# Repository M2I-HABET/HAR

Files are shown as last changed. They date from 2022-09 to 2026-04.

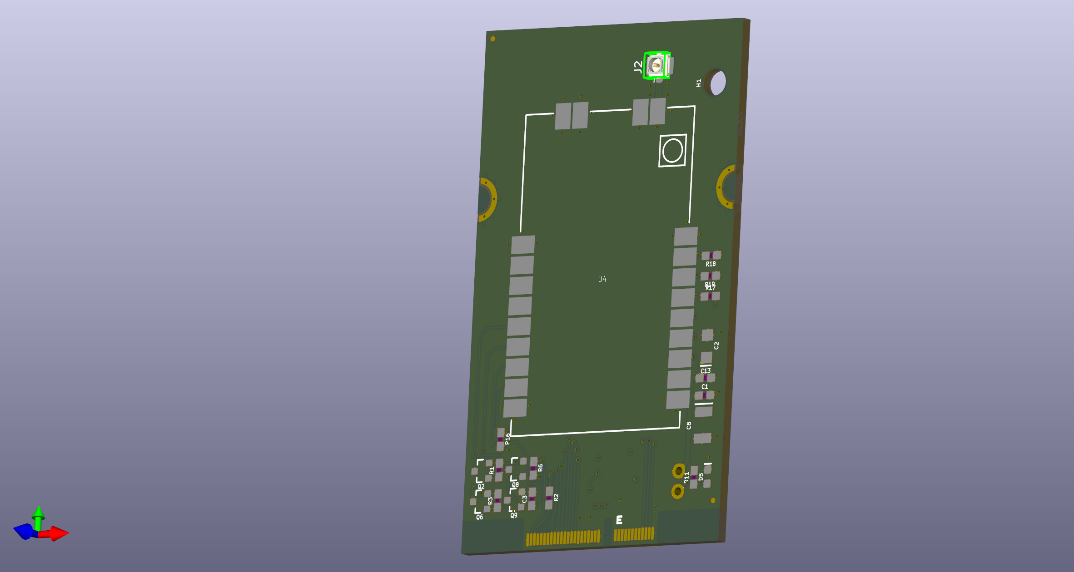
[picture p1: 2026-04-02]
HAR PCB update/MicroMod-LoRa-1W-Function-Board.png

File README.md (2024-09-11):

# High Altitude Reporter (HAR)

HAR is named after the Norse god HÁR, the Norse god of knowledge whose name means "high." It seemed fitting then that we name our main onboard computer HAR.  HAR is used to gather data, store data, transmit data, and perform other housekeeping needs to keep the spacecraft functional through all stages of flight.

# Electrical Specification

HAR is the primary avionics system for all HABET missions. It provides a processing system, sensors, and communication functions to support all spacecraft missions.

## Electrical Overview

For all HABET missions, a few key things are needed to carry out a successful mission. To be successful, we need to have a system that allows us to track the spacecraft, communicate with the spacecraft, process sensor data, and manage power.

Generally speaking, Power and some sort of data management is usually the bare minimum needed for most payloads. However, many payloads either benefit or require the additional items listed. Therefore, Athena was designed with all of the items listed. As of the date of this document, the following features are currently provided.

| Feature | Specification |
| --- | --- |
| Power |  |
| LoRa Data link | 115,200 bps |
| Data Storage | Up to 2GB per payload |
| Data downlink | 1 packet every 4 seconds or higher. 1 packet must be under 256 bytes |
| Data uplink | 1 packet every 10 seconds or higher, 1 packet must be under 256 bytes |
| GPS Data | NMEA of the GPGGA string is available at 9600 bps |
| Video monitoring | Video stored onboard at 720p |

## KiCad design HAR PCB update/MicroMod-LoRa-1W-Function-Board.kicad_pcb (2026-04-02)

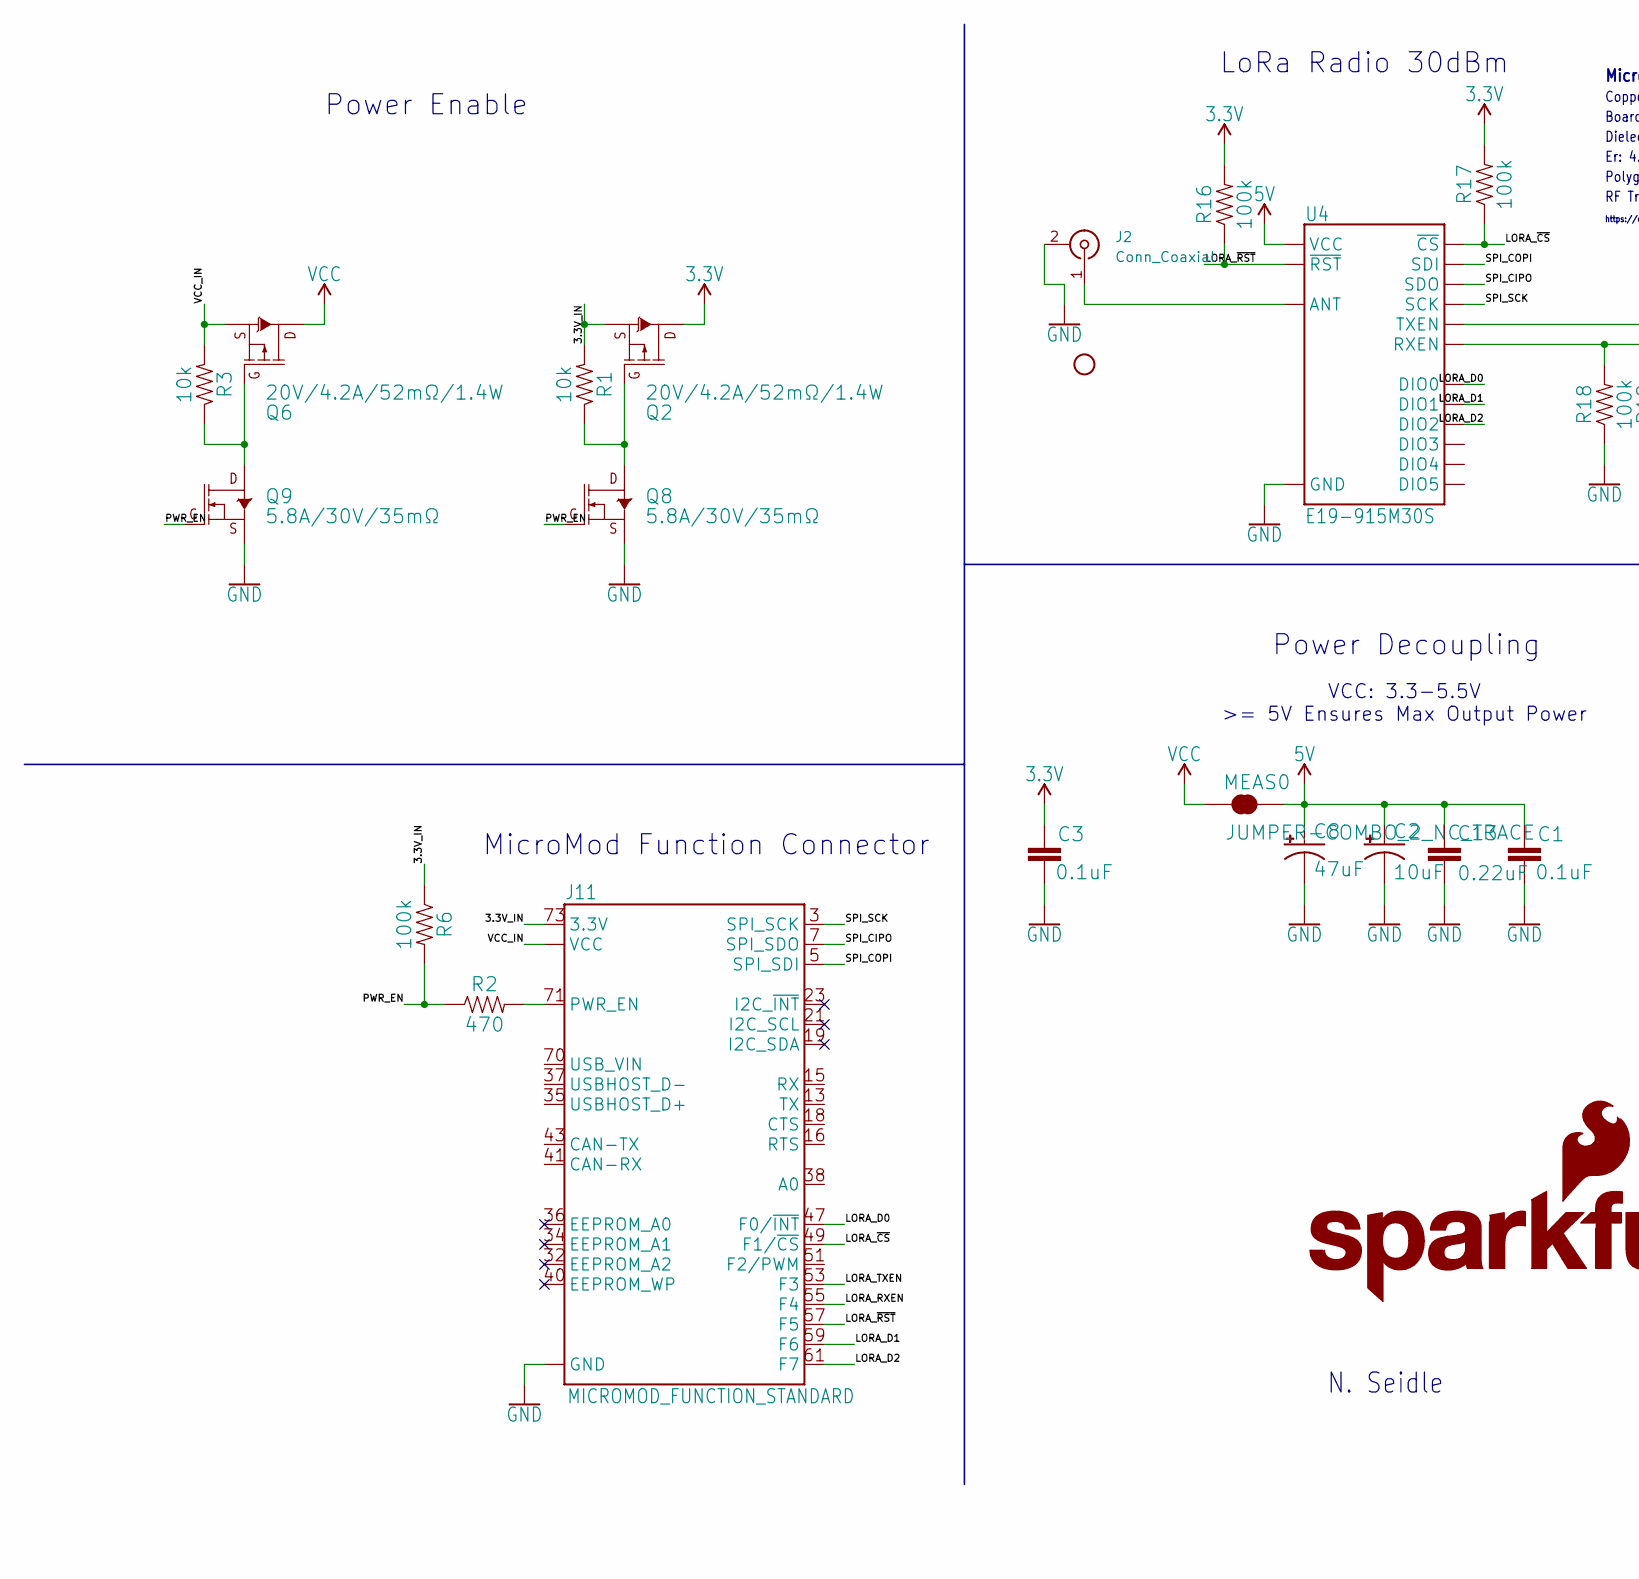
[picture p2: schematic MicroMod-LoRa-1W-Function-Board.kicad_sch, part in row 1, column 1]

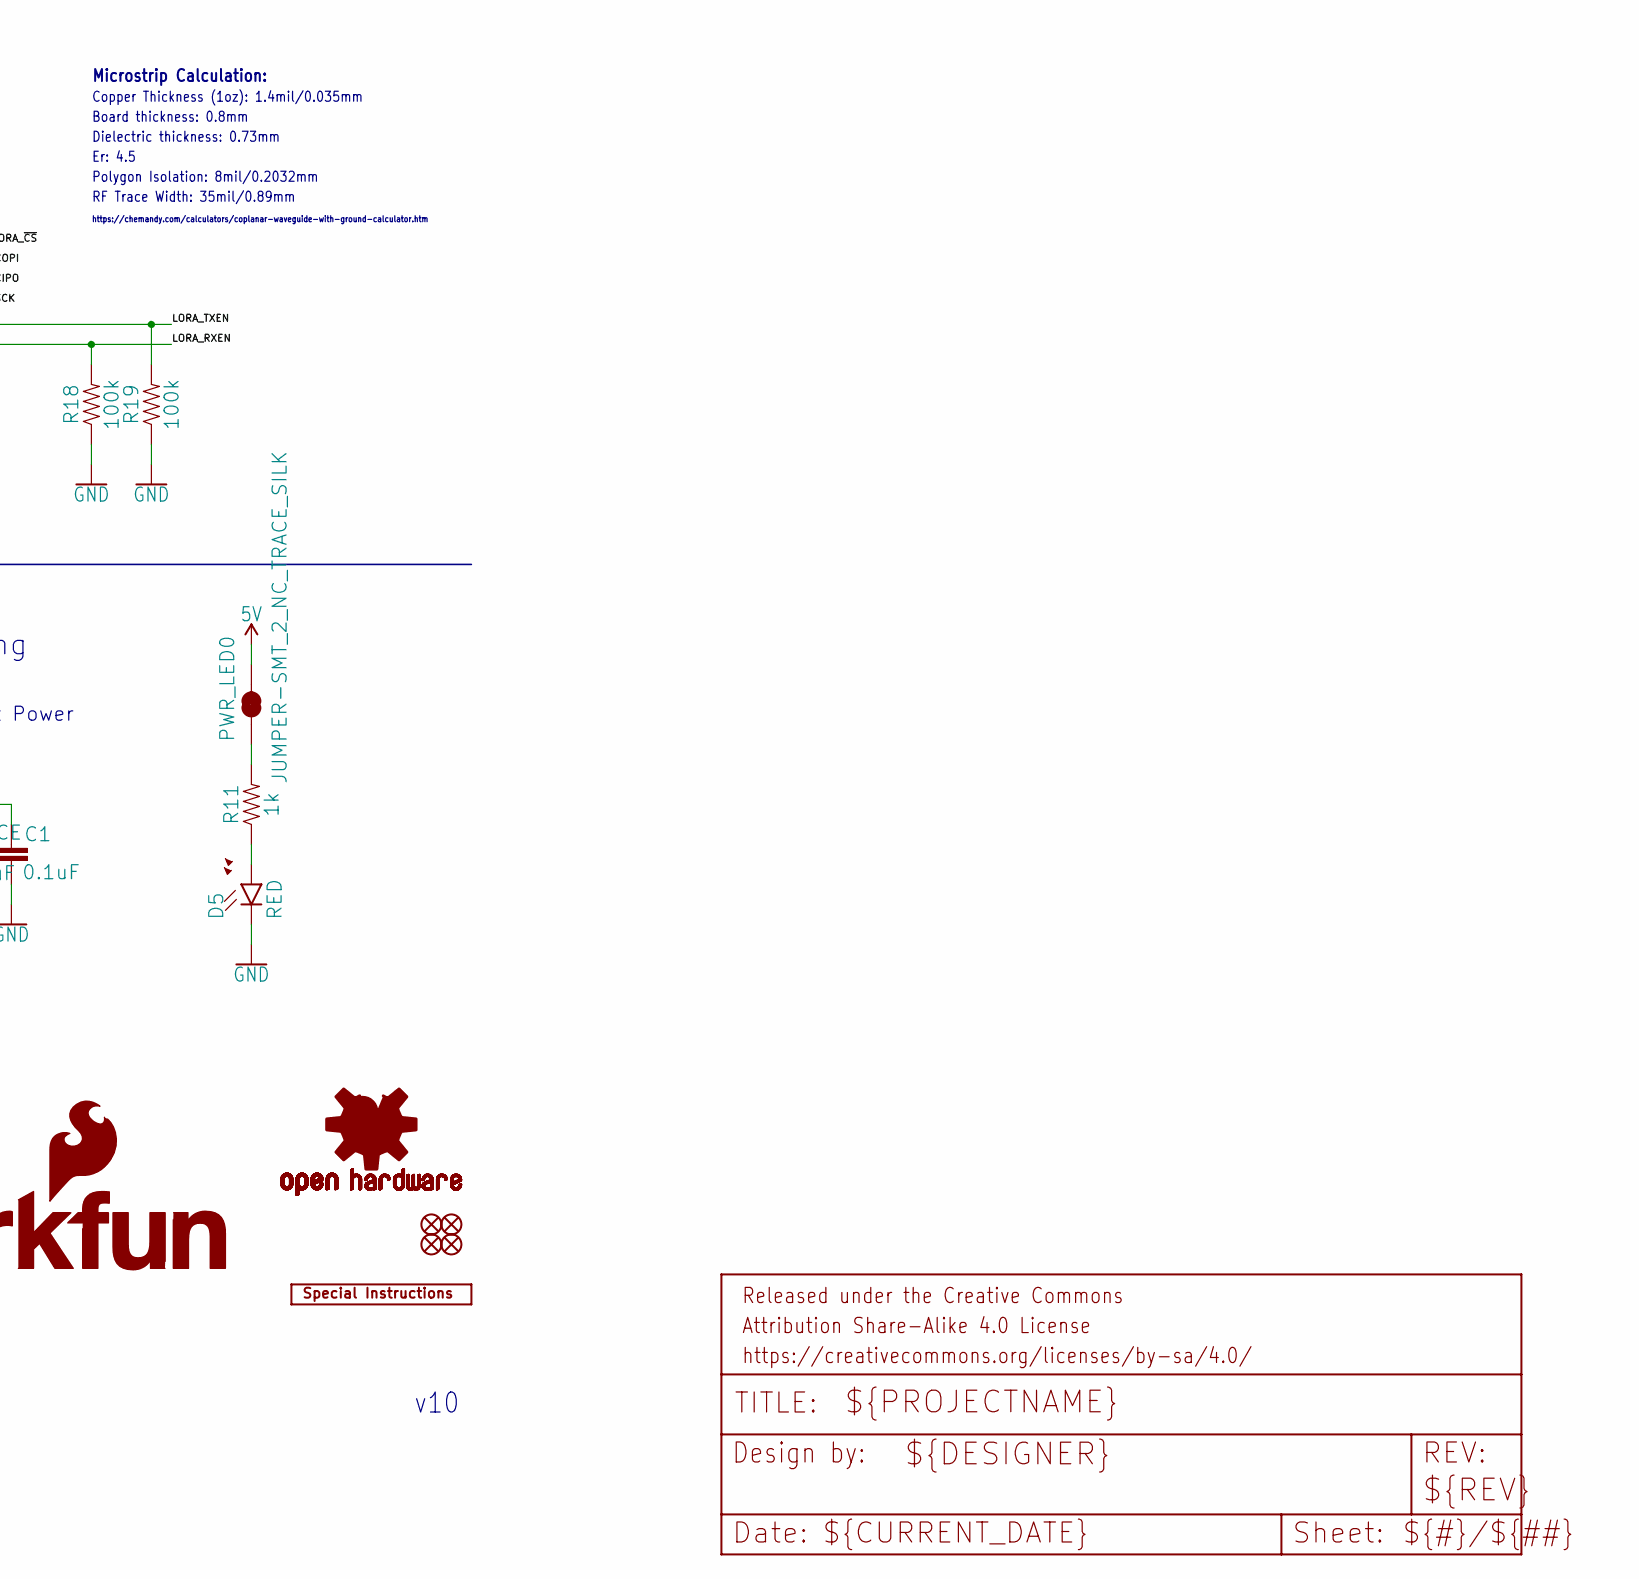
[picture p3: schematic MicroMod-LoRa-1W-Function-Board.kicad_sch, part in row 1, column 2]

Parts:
C1, C3: 0.1uF; 0603
C2: 10uF; EIA3216
C8: 47uF; EIA3528
C13: 0.22uF; 0603
D5: RED; LED-0603
FD1, FD2, FD3, FD4: FIDUCIALUFIDUCIAL; FIDUCIAL-MICRO
FRAME2: FRAME-LETTER; CREATIVE_COMMONS
H1: STAND-OFF
J2: Conn_Coaxial; U.FL_Hirose_U.FL-R-SMT-1_Vertical
J11: MICROMOD_FUNCTION_STANDARD; M.2-CARD-E-22_FUNCTION_STANDARD
LOGO1: SFE_LOGO_NAME_FLAME.1_INCH; SFE_LOGO_NAME_FLAME_.1
LOGO2: SPECIAL_INSTRUCTIONS-ORDERING; ORDERING_INSTRUCTIONS
LOGO3: OSHW-LOGOMINI; OSHW-LOGO-MINI
MEAS0: JUMPER-COMBO_2_NC_TRACE; COMBO-JUMPER_2_NC_TRACE
PWR_LED0: JUMPER-SMT_2_NC_TRACE_SILK; SMT-JUMPER_2_NC_TRACE_SILK
Q2, Q6: 20V/4.2A/52mΩ/1.4W; SOT23-3
Q8, Q9: 5.8A/30V/35mΩ; SOT23-3
R1, R3: 10k; 0603
R2: 470; 0603
R6, R16, R17, R18, R19: 100k; 0603
R11: 1k; 0603
U4: E19-915M30S; E19-915MS1W

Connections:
3.3V: C3.1, Q2.3 (D), R16.2, R17.2
5V: C1.1, C2.+, C8.A (+), C13.1, MEAS0.2, MEAS0.4 (2), PWR_LED0.2, U4.11 (VCC)
/3.3V_IN: J11.73 (3.3V), Q2.2 (S), R1.2, R6.1
/LORA_D0: J11.47 (F0/~INT), U4.7 (DIO0)
/LORA_D1: J11.59 (F6), U4.6 (DIO1)
/LORA_D2: J11.61 (F7), U4.5 (DIO2)
/LORA_RXEN: J11.55 (F4), R18.2, U4.17 (RXEN)
/LORA_TXEN: J11.53 (F3), R19.2, U4.16 (TXEN)
/LORA_~CS: J11.49 (F1/~CS), R17.1, U4.15 (~CS)
/LORA_~RST: J11.57 (F5), R16.1, U4.8 (~RST)
/PWR_EN: Q8.1 (G), Q9.1 (G), R2.1, R6.2
/SPI_CIPO: J11.7 (SPI_SDO), U4.13 (SDO)
/SPI_COPI: J11.5 (SPI_SDI), U4.14 (SDI)
/SPI_SCK: J11.3 (SPI_SCK), U4.12 (SCK)
/VCC_IN: J11.72 (VCC), J11.74 (VCC), Q6.2 (S), R3.2
GND: C1.2, C2.-, C3.2, C8.C (-), C13.2, D5.C, J2.2 (Ext), J11.1 (GND), J11.33 (GND), J11.39 (GND), J11.45 (GND), J11.75 (GND), J11.GND1 (GND), J11.GND2 (GND), J11.GND3 (GND), J11.GND4 (GND), J11.GND5 (GND), J11.GND6 (GND), Q8.2 (S), Q9.2 (S), R18.1, R19.1, U4.1 (GND), U4.9 (GND), U4.10 (GND), U4.18 (GND), U4.20 (GND), U4.21 (GND), U4.22 (GND)
unnamed: D5.A, R11.1
unnamed: J2.1 (In), U4.19 (ANT)
unnamed: J11.71 (PWR_EN), R2.2
unnamed: PWR_LED0.1, R11.2
unnamed: Q2.1 (G), Q8.3 (D), R1.1
unnamed: Q6.1 (G), Q9.3 (D), R3.1
VCC: MEAS0.1, MEAS0.3 (1), Q6.3 (D)

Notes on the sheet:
N. Seidle
MicroMod Function Connector
Dielectric thickness: 0.73mm
https://chemandy.com/calculators/coplanar-waveguide-with-ground-calculator.htm
RF Trace Width: 35mil/0.89mm
LoRa Radio 30dBm
Board thickness: 0.8mm
Polygon Isolation: 8mil/0.2032mm
Power Decoupling
Copper Thickness (1oz): 1.4mil/0.035mm
Power Enable
v10
Microstrip Calculation:
Er: 4.5
VCC: 3.3-5.5V >= 5V Ensures Max Output Power

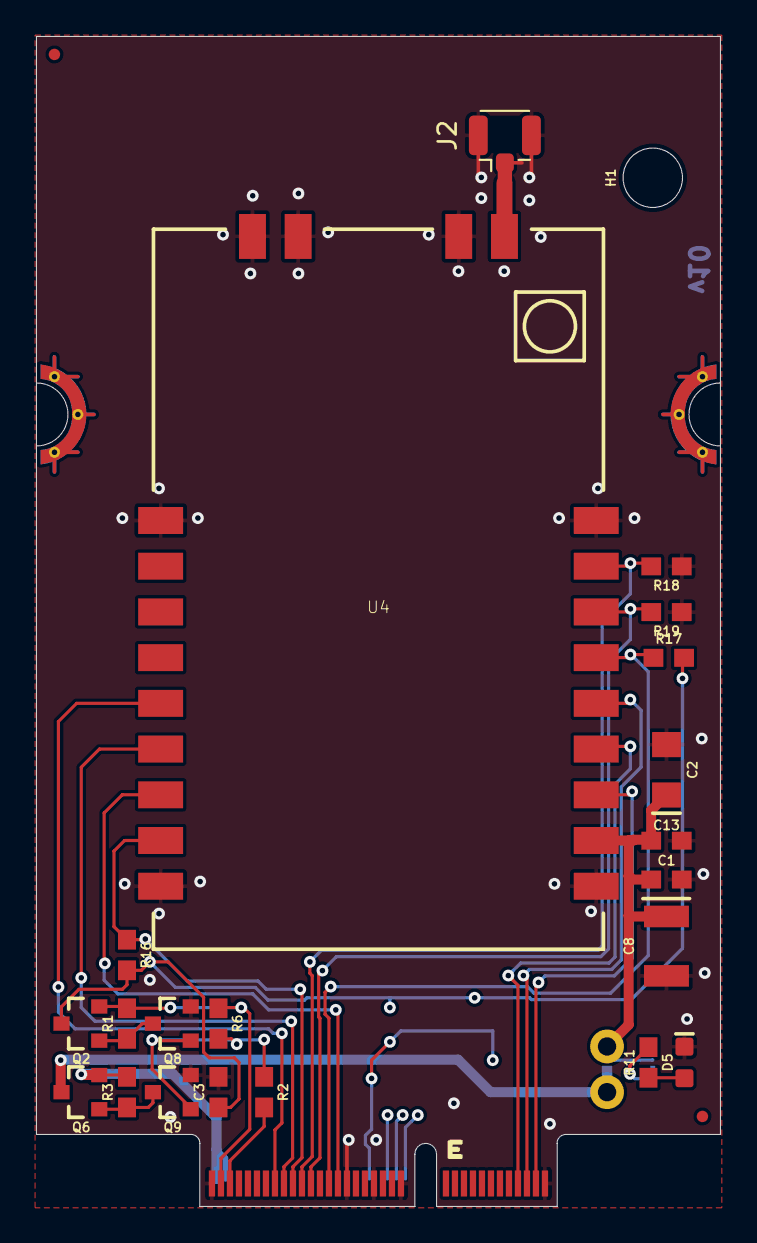
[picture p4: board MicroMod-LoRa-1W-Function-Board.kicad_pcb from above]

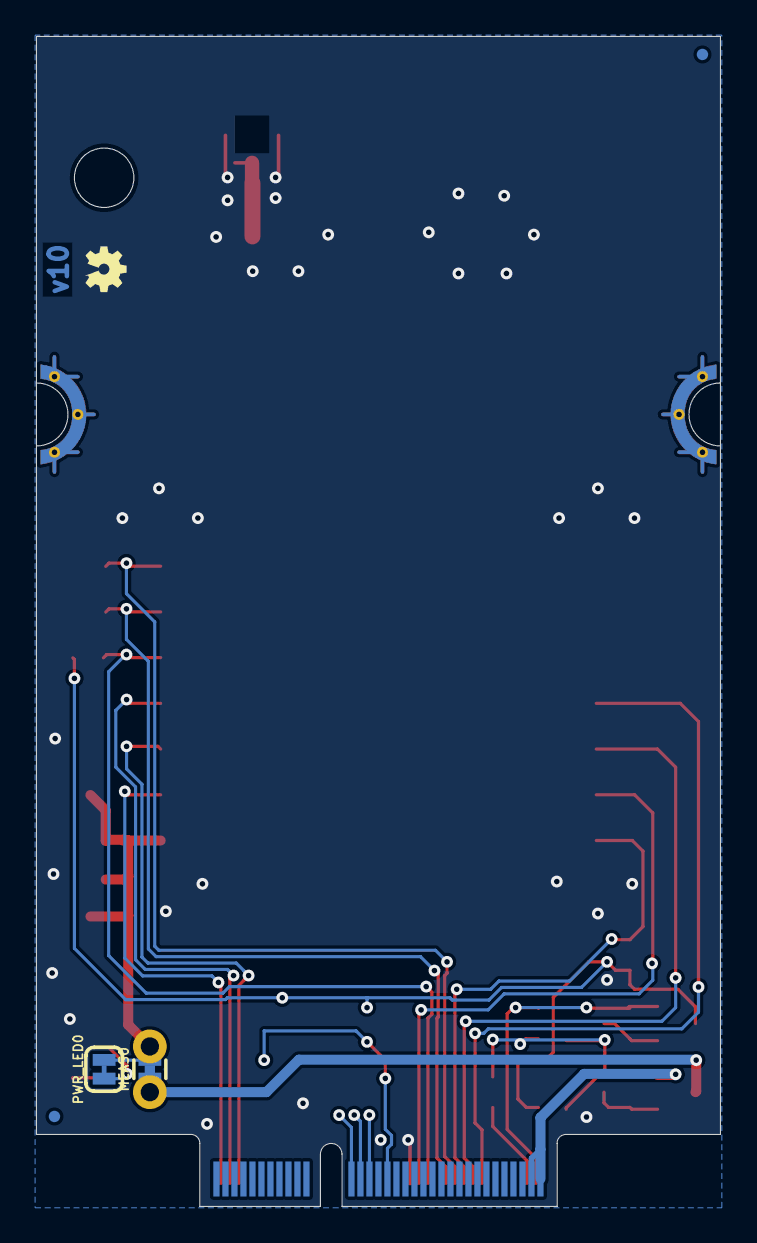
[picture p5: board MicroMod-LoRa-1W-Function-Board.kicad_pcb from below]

Board: 2 copper layers, 38.0 x 65.0 mm, 32 parts (5 on the bottom side), 23 nets.

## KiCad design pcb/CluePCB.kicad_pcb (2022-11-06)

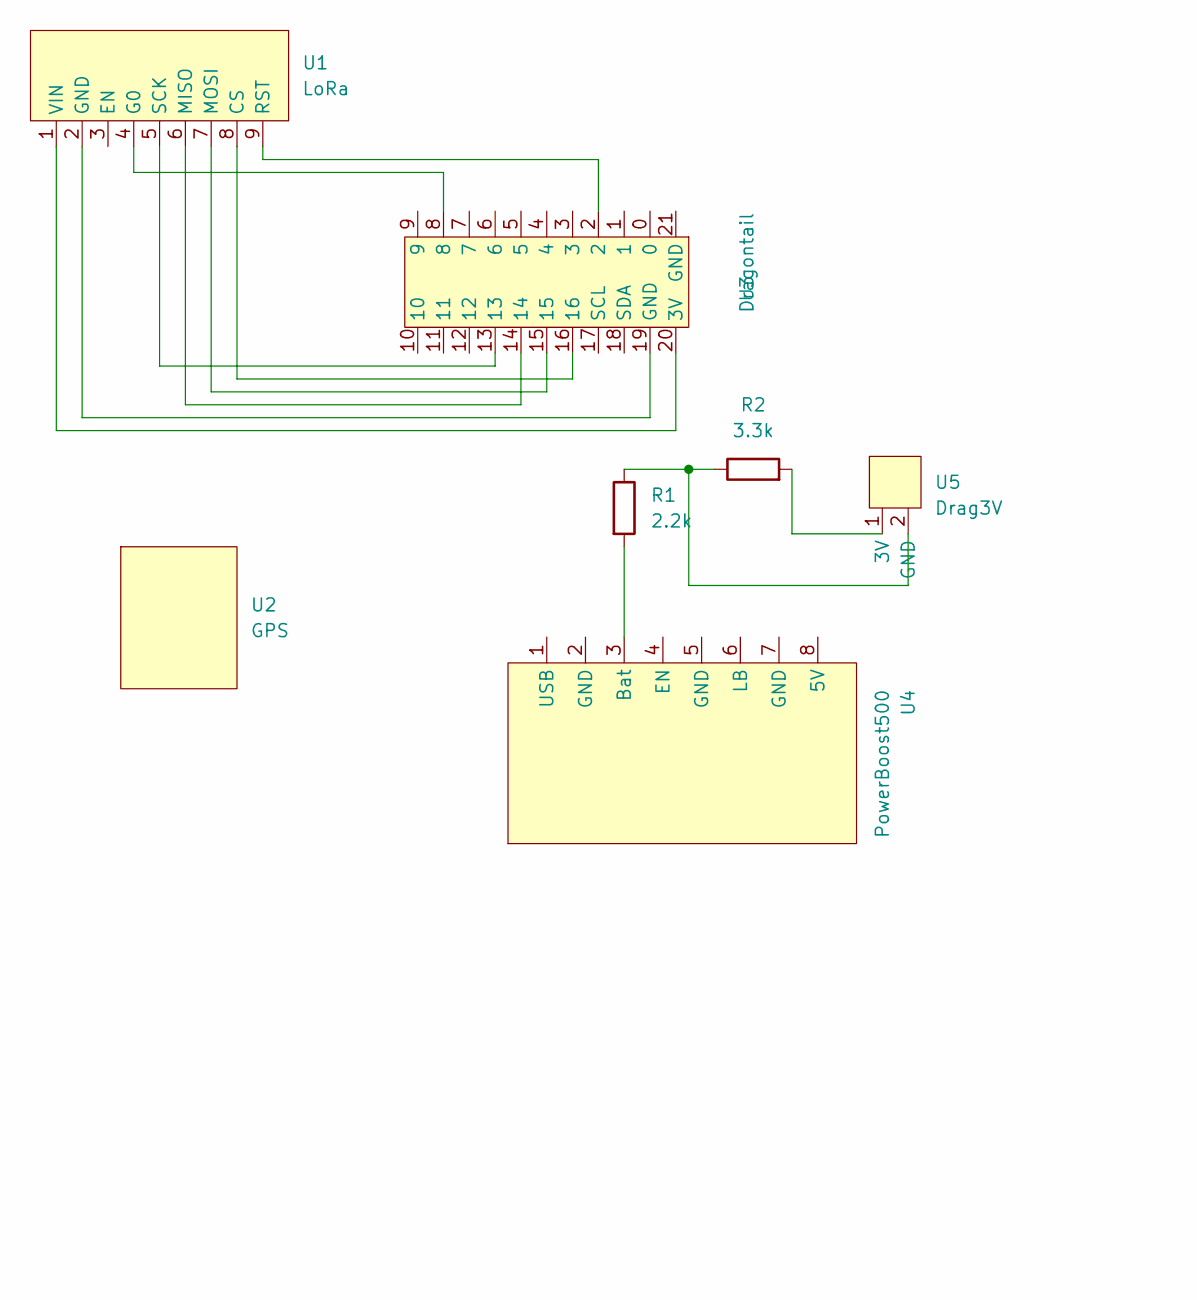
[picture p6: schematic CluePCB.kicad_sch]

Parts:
R1: 2.2k; R_Axial_DIN0204_L3.6mm_D1.6mm_P5.08mm_Horizontal
R2: 3.3k; R_Axial_DIN0204_L3.6mm_D1.6mm_P5.08mm_Horizontal
U1: LoRa
U2: GPS
U3: Dragontail
U4: PowerBoost500; Powerboost500
U5: Drag3V; Dragon3V

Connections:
unnamed: R1.1, R2.1
unnamed: R1.2, U4.3 (Bat)
unnamed: U1.1 (VIN), U3.20 (3V)
unnamed: U1.2 (GND), U3.19 (GND)
unnamed: U1.4 (G0), U3.8
unnamed: U1.5 (SCK), U3.13
unnamed: U1.6 (MISO), U3.14
unnamed: U1.7 (MOSI), U3.15
unnamed: U1.8 (CS), U3.16
unnamed: U1.9 (RST), U3.2

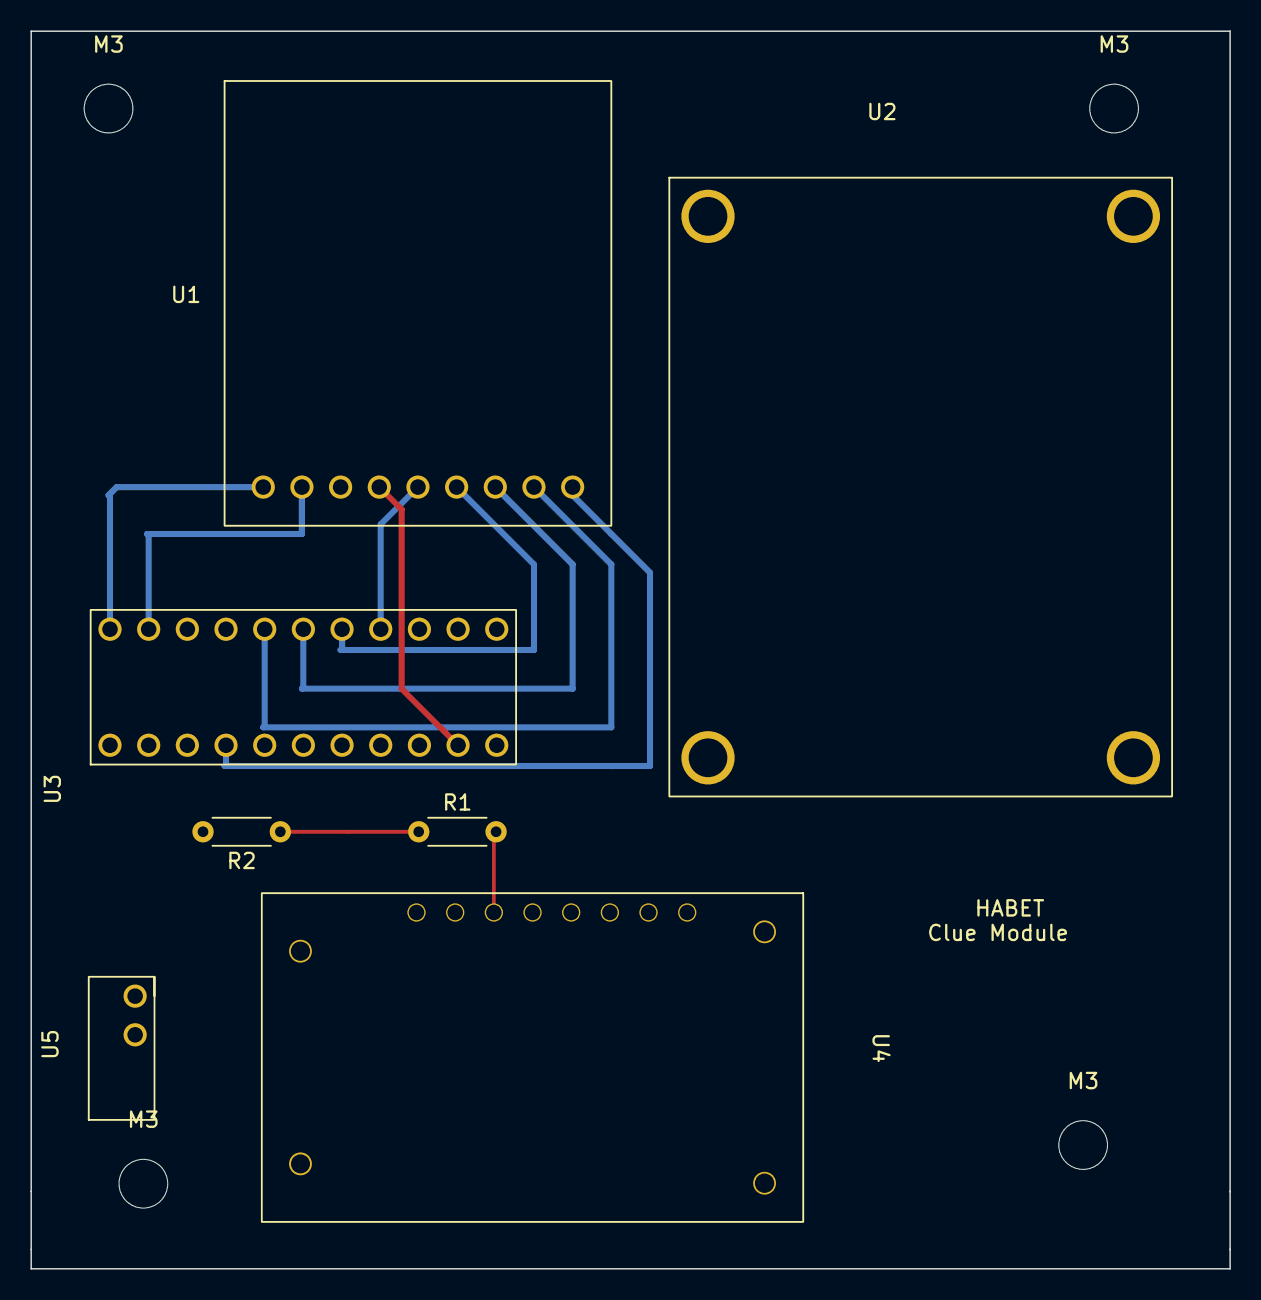
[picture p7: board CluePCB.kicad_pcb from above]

Board: 2 copper layers, 78.7 x 81.3 mm, 11 parts (0 on the bottom side), 10 nets.

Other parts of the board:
M3, M3#2, M3#3, M3#4: MountingHole; MountingHole_3.2mm_M3

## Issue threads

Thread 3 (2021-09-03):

Add additional sensors

matgyver, 2021-09-03:
Add additional sensor data that is stored on the flash memory. Add the IMU data to the data stored.

matgyver, 2022-10-10:
Closing this for now. Added all sensors except for the light sensor. Resolved in #5

Closed 2022-10-10.

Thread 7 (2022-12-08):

Add power management

matgyver, 2022-12-08:
Add a power management circuit to monitor voltage, current, and power consumption. Add data to the LoRa data stream and to the flash storage.

matgyver, 2023-02-20:
Added power monitor to HW in #9

matgyver, 2023-02-20:
Added power reading in FW in #10

matgyver, 2024-08-29:
Closing this out as this is for an older iteration.

Closed 2024-08-29.

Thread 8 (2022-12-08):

Look into new Hardware base

matgyver, 2022-12-08:
While the Clue board has been a good start, a few issues have come up where we might want to switch to a different hardware base.

matgyver, 2023-10-18:
Switched to new Sparkfun M.2 hardware system

Closed 2023-10-18.

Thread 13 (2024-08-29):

Monitor battery voltage

matgyver, 2024-08-29:
The Sparkfun MicroMod board we have does not have a line from the battery input to an A/D pin. We can monitor the voltage when the USB-C is plugged in, but not from the battery (which is more critical). See if we can modify the board or this may need to get rolled into a new custom board for HAR for Rev 6.

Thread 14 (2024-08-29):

SD Card not detected on startup

matgyver, 2024-08-29:
At times, HAR will go to initialize the SD Card and then fail. When this happens, HAR then goes into an infinite loop as the watchdog will kick-in and reboot the board, but then it can't find the SD Card isn't found and the cycle continues.

## Desired Operation
1. Scan for SD Card
2. If SD Card is present, continue and illuminate a Green status LED
3. If SD Card is *not* present, then give error message, illuminate a red status LED and continue

This way, if the SD Card failure happens in flight and a reboot is triggered, at HAR will continue to transmit position via LoRa.

## Secondary Task
Investigate on why we are getting SD Card failures. Right now, we have to hard reboot the board to get it to work. It does not appear to be an issue with the SD Card holder. Instead it seems to be either on initialization so either software or something with the SPI bus.

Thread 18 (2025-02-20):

HAR Display

matgyver, 2025-02-20:
HAR needs a quick and easy to let operation teams know the status of HAR. When we were using the Clue Board, this was easy as the Clue Board had a built-in display. We need to add something like that (durability may be an issue) or have a different system (just LEDs) or something in between.

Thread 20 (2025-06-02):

LoRa Power Output

matgyver, 2025-06-02:
Output from the SX1276 modules from Spark fun do not seem to outputting the full 1 watt. This may be due to a library issue or could be hardware. Investigate the issue.

matgyver, 2025-06-17:
Re-opening issue due to new discovery that this was in fact a library issue.

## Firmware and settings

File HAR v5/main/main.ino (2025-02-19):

/*
   HAR v5.0 (MicroMod)

   Main program to be run on version 5.0 of HABET's High Altitude Reporter (HAR).
   Handles intake of GPS and sensor data and outputs over 915 MHz LoRa module to
   ground station, as well as storing to onboard SD card. Requires MicroMod GNSS Function Board (Function One), 
   1W LoRa MicroMod Function Board (Function Zero), and a MicroMod ESP32 Processor. Future updates will 
   include use of ESP32's built-in WiFi transceiver to communicate with other onboard devices.

   *IMPORTANT NOTE*: Do not plug in the GNSS Function Board on the Function One slot until the board is
   programmed. The ESP32 will not be able to talk to its attached flash chip which will result in a fatal
   error. This is because the Function One slot uses the GPIO pins 6-11, which the ESP32 requires to be
   open.

   Created by Nick Goeckner and Brandon Beavers
   M2I HABET
   Date Created: July 13, 2023
   Last Updated: March 1, 2024
*/
#include <Arduino.h>
#include <RadioLib.h> //Click here to get the library:    https://jgromes.github.io/RadioLib/
#include <SparkFun_u-blox_GNSS_Arduino_Library.h> // Library found here: https://github.com/sparkfun/SparkFun_u-blox_GNSS_Arduino_Library 
#include <Zanshin_BME680.h>
#include <Wire.h>
#include <SPI.h>
#include <SD.h>
#include <Adafruit_SleepyDog.h>

// Redefine CS Pin Name
// SPI_CS0:     ESP32
// SS:          ESP32, nRF, RP2040
// SPI_CS:      Artemis
// PIN_SPI_SS:  STM32, SAMD51, nRF, RP2040

#ifndef PIN_SPI_SS
  // For Artemis
  #ifdef SS
    #define PIN_SPI_SS SPI_CS
  #endif
  // For ESP32
  #ifdef SPI_CS0
    #define PIN_SPI_SS SS
  #endif
#endif


SFE_UBLOX_GNSS GNSS;//
BME680_Class BME680;
// SX1276 pin connections:
//       | SLOT 0 | SLOT 1 |
//==========================
// cs    |   CS0  |   CS1  |
// dio0  |   D0   |   D1   |
// dio1  |   G2   |   G7   |
// dio2  |   G3   |   G8   |
// rst   |   G1   |   G6   |
// tx_en |  PWM0  |  PWM1  |
// rx_en |   G0   |   G5   |

int pin_cs =        PIN_SPI_SS;
int pin_dio0 =      D0;
int pin_tx_enable = PWM0;
int pin_rx_enable = G0;
int pin_nrst =      G1;
int pin_dio1 =      G2;
int ledPin =        2;
int battPin =       39;
  
SX1276 radio = new Module(pin_cs, pin_dio0, pin_nrst, pin_dio1);

// Initializes radio, serial, GPS, and I2C bus:
void setup() {
  // Status light:
  pinMode(ledPin, OUTPUT);
  // Serial:
  Serial.begin(115200);
  // I2C:
  Wire.begin();
  // Watchdog:
  Serial.println("Setting up WatchDog...");
  int countdownMS = Watchdog.enable(10000);
  Serial.print("Enabled the watchdog with max countdown of ");
  Serial.print(countdownMS, DEC);
  Serial.println(" milliseconds!");
  // GPS:
  Serial.print(F("[NEO-M9N] Initializing..."));
  //if (GNSS.begin() == false){
  //  Serial.println(F("u-blox GNSS not detected. Freezing."));
  //  while (1);  
  //}
  GNSS.begin();
  GNSS.setI2COutput(COM_TYPE_UBX); // Outputting UBX (U-blox binary protocol) only, no NMEA (National Marine Electronics Association)
  GNSS.setDynamicModel(DYN_MODEL_AIRBORNE2g); // Sets dynamic model to AIRBORNE2g. Other options: PORTABLE, STATIONARY, PEDESTRIAN, AUTOMOTIVE, SEA, AIRBORNE1g, AIRBORNE4g, WRIST, BIKE
  Serial.println(F("init success!"));
  delay(500);
  //SD Card Initialization:
  Serial.print("Initializing SD card...");
  if (!SD.begin(16)) {
    Serial.println("initialization failed!");
    while (1);
  }
  Serial.println("init success!");
  // Radio: 
  Serial.print(F("[SX1276] Initializing ... "));
  int state = radio.begin(915.0); //-23dBm
  if (state == RADIOLIB_ERR_NONE) {
    Serial.println(F("init success!"));
  } else {
    Serial.print(F("failed, code "));
    Serial.println(state);
    while (true);
  }
  radio.setOutputPower(30); // sets output power to 30 dBm - needs testing (may overheat!)
  // BME-680:
  while (!BME680.begin(I2C_STANDARD_MODE)) {  // Start BME680 using I2C, use first device found
    Serial.print(F("-  Unable to find BME680. Trying again in 5 seconds.\n"));
    delay(5000);
  }
  Serial.print(F("- Setting 16x oversampling for all sensors\n"));
  BME680.setOversampling(TemperatureSensor, Oversample16);  // Use enumerated type values
  BME680.setOversampling(HumiditySensor, Oversample16);     // Use enumerated type values
  BME680.setOversampling(PressureSensor, Oversample16);     // Use enumerated type values
  Serial.print(F("- Setting IIR filter to a value of 4 samples\n"));
  BME680.setIIRFilter(IIR4);  // Use enumerated type values
  Serial.print(F("- Setting gas measurement to 320\xC2\xB0\x43 for 150ms\n"));  // "�C" symbols
  BME680.setGas(320, 150);  // 320�c for 150 milliseconds

  radio.setRfSwitchPins(pin_rx_enable, pin_tx_enable);
  delay(100);
}

// initialize data variables here:
// Packet counter:
int counter = 0;
// GPS:
long GPSLat = 0;
long GPSLon = 0;
long GPSAlt = 0;
long GPSHour = 0;
long GPSMinute = 0;
long GPSSecond = 0;
long GPSSpeed = 0;
long GPSHeading = 0;
int GPSPDOP = 0;
// BME 680:
int temp = 0;
int pressure = 0;
int humidity = 0;
int gas = 0;
int batt = 0;
float volt;

int var = 0;
byte cmd2[] = {0xFF,0x28,0x01,0x00, 0x00}; // replace end value w/ checksum
byte cmd3[] = {0xFF,0x28,0x19,0x01,10800, 0x00}; // replace end value w/ checksum
byte cmd4[] = {0xFF,0x28,0x17,0x00, 0x00}; // replace end value w/ checksum
byte byteArr[1];


void loop() {
  // Receive:
  String str;
  //Serial.print(F("[SX1276] Starting to listen ... "));
  int receiverState = radio.receive(byteArr, 1);
  var = byteArr[0];
  if (receiverState == RADIOLIB_ERR_NONE) {
    //Serial.println(F("success!"));
    counter++;
    switch (var){
      case 1:
        digitalWrite(ledPin, HIGH);
        delay(500);
        digitalWrite(ledPin, LOW);
        delay(500);
        var = 0;
        break;
      case 2:
        Serial.write(cmd2, 5);
        var = 0;
        break;
      case 3:
        Serial.write(cmd3, 6);
        var = 0;
        break;
      case 4:
        Serial.write(cmd4, 5);
        var = 0;
        break;
      default:
        Serial.println("ERROR: Command not recognized");
        break;  
    }
  } else if (receiverState == RADIOLIB_ERR_RX_TIMEOUT) {
    // timeout occurred while waiting for a packet
    //Serial.println(F("timeout!"));

  } else if (receiverState == RADIOLIB_ERR_CRC_MISMATCH) {
    // packet was received, but is malformed
    //Serial.println(F("CRC error!"));

  } else {
    //Serial.print(F("failed, code "));
    //Serial.println(receiverState);
    while (true);
  }

  // Transmit:
  if (GNSS.getPVT()){
    GPSLat = GNSS.getLatitude(); // divide Lat/Lon by 1000000 to get coords
    GPSLon = GNSS.getLongitude();
    GPSAlt = GNSS.getAltitude(); // measures in mm. Divide by 1000 for alt in m
    // grab time from GPS - NOTE 10/4/23 - Not currently in use as requires changes to ground station tracker
    GPSHour = GNSS.getHour();
    GPSMinute = GNSS.getMinute();
    GPSSecond = GNSS.getSecond();

    // grab heading, ground speed, and dilution of precision data
    GPSHeading = GNSS.getHeading(); //measurement in degrees * 10^-5
    GPSSpeed = GNSS.getGroundSpeed(); // measurement in mm/s
    GPSPDOP = GNSS.getPDOP(); 
  }

  // get atmospheric data
  BME680.getSensorData(temp, humidity, pressure, gas);

  // Get Battery Data

  batt = analogRead(battPin);
  volt = (analogRead(battPin) * (3.3 / 4096)) * 3;
  
  // you can transmit C-string or Arduino string up to
  // 256 characters long

  char output[256];
  sprintf(output, "$$HAR, %d, %d, %d, %d, %d, %d, %d, %d, %d, %d, %.2f", GPSLat, GPSLon, GPSAlt, GPSHeading, GPSSpeed, GPSPDOP, pressure, temp, humidity, counter,volt);
  File file = SD.open("/HARdata.csv", FILE_APPEND);
  file.print("$$HAR,");
  file.print(GPSHour);
  file.print(":");
  file.print(GPSMinute);
  file.print(":");
  file.print(GPSSecond);
  file.print(",");
  file.print(GPSLat);
  file.print(",");
  file.print(GPSLon);
  file.print(",");
  file.print(GPSAlt);
  file.print(",");
  file.print(GPSHeading);
  file.print(",");
  file.print(GPSSpeed);
  file.print(",");
  file.print(GPSPDOP);
  file.print(",");
  file.print(pressure);
  file.print(",");
  file.print(temp);
  file.print(",");
  file.println(humidity);
  file.close();

  Serial.println(output);
  //Serial.println(GPSPDOP);
  int state = radio.transmit(output);
  //Serial.print(F("[SX1276] Transmitting packet ... "));
  if (state == RADIOLIB_ERR_NONE) {
    // the packet was successfully transmitted
    //Serial.println(F(" success!"));

    // print measured data rate
    //Serial.print(F("[SX1276] Datarate:\t"));
    //Serial.print(radio.getDataRate());
    //Serial.println(F(" bps"));

  } else if (state == RADIOLIB_ERR_PACKET_TOO_LONG) {
    // the supplied packet was longer than 256 bytes
    //Serial.println(F("too long!"));

  } else if (state == RADIOLIB_ERR_TX_TIMEOUT) {
    // timeout occurred while transmitting packet
    //Serial.println(F("timeout!"));

  } else {
    // some other error occurred
    //Serial.print(F("failed, code "));
    //Serial.println(state);
  }
  // clears RAM allocated to PVT processing - needs testing, might require re-initializing GPS every loop
  //GNSS.end();
  // reset watchdog timer
  Watchdog.reset();
  // wait for a second before transmitting again
  delay(1000);
}

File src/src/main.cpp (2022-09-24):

/*!
 * High Altitude Reporter (HAR)
 * HW Version - 0.1
 * FW Version - 0.3
 * Matthew E. Nelson
 */

/*!
  @brief     Main Functions
  @details   Main function handles the timer functions which times when certain tasks
             are called. 

             
********HARDWARE REQUIREMENTS*****************
  - Adafruit Clue Board
  - Sparkfun Neo GPS Unit 
  - Adafruit LoRa board

Hardware hookup is via QWICC Connector
(CLUE <-> [QWIIC] <----> [QWIIC] <-> Sparkfun GPS BOB
   ^
   |Micro::Bit breakout board
   |LoRa Breakout Board

  @note - Clue board requires 3-6 VDC (different from Micro:bit) Recommend using 3 AA or Boost board
 */

#include <Arduino.h>

#include <Adafruit_Arcada.h>
#include <Adafruit_SPIFlash.h>
#include <Adafruit_SleepyDog.h>
//#include <Wire.h> //Needed for I2C to GNSS GPS
#include <Adafruit_GFX.h>    // Core graphics library
#include <Adafruit_ST7789.h> // Hardware-specific library for ST7789
#include <Adafruit_Sensor.h>

#include <RH_RF95.h>

#include <time.h>
#include "hardware.h"

/**************************************************************************************************
** Declare global variables and instantiate classes                                              **
**************************************************************************************************/
//set to true to see all serial outputs, otherwise only errors are sent out
#define DEBUG true

// Instantiates functions for hardware
Adafruit_Arcada arcada;

extern Adafruit_FlashTransport_QSPI flashTransport;
extern Adafruit_SPIFlash Arcada_QSPI_Flash;

// file system object from SdFat
FatFileSystem fatfs;

// Configuration for the datalogging file:
#define FILE_NAME  "HAR_FDR.csv"

// Check the timer callback, this function is called every millisecond!
volatile uint16_t milliseconds = 0;
void timercallback() {
  analogWrite(LED_BUILTIN, milliseconds);  // pulse the LED
  if (milliseconds == 0) {
    milliseconds = 255;
  } else {
    milliseconds--;
  }
}

unsigned long myTime;
unsigned long lastTime = 0; //Simple local timer.
unsigned long lastTime2 = 0; //Simple local timer. Limits amount if I2C traffic to u-blox module.

void setup() {
  Serial.begin(115200);
  delay(100);
  Serial.println("--------------------------------------------");
  //delay(5000);
  Serial.println("High Altitude Reporter OS (HAROS)");
  Serial.println("============================================");
  Serial.println(" HW Rev. 1.0 | FW Rev. 1.2");
  Serial.println("============================================");
  delay(2000);
  init_i2c(DEBUG);
  Serial.println("Setting up WatchDog...");
  int countdownMS = Watchdog.enable(10000);
  Serial.print("Enabled the watchdog with max countdown of ");
  Serial.print(countdownMS, DEC);
  Serial.println(" milliseconds!");
  Serial.println();
  #ifndef NRF52_SERIES // cannot disable nRF's WDT
    // Disable the watchdog entirely by calling Watchdog.disable();
    Watchdog.disable();
  #endif 
  pinMode(WHITE_LED, OUTPUT);
  digitalWrite(WHITE_LED, LOW);
  if (!arcada.arcadaBegin()) {
      Serial.println("Failed to start Arcada!");
      while (1);
  }
  arcada.displayBegin();

  for (int i=0; i<250; i+=10) {
      arcada.setBacklight(i);
      delay(1);
  }
  arcada.display->setCursor(0, 0);
  arcada.display->setTextWrap(true);
  arcada.display->setTextSize(2);
  arcada.display->setTextColor(ARCADA_GREEN);
  arcada.display->println("HAROS Booting up...");
  arcada.display->println("FW Rev: 1.2");
  /********** Check QSPI manually */
  if (!Arcada_QSPI_Flash.begin()){
    Serial.println("Could not find flash on QSPI bus!");
    arcada.display->setTextColor(ARCADA_RED);
    arcada.display->println("QSPI Flash FAIL");
  } else {
    uint32_t jedec;
    jedec = Arcada_QSPI_Flash.getJEDECID();
    Serial.print("JEDEC ID: 0x"); Serial.println(jedec, HEX);
    arcada.display->setTextColor(ARCADA_GREEN);
    arcada.display->print("QSPI JEDEC: 0x"); arcada.display->println(jedec, HEX);
  }
  
   /********** Check filesystem next */
  if (!arcada.filesysBegin()) {
    Serial.println("Failed to load filesys");
    arcada.display->setTextColor(ARCADA_YELLOW);
    arcada.display->println("Filesystem not found");
  } else {
    Serial.println("Filesys OK!");
    arcada.display->setTextColor(ARCADA_GREEN);
    arcada.display->println("Filesystem OK");
  }
  // First call begin to mount the filesystem.  Check that it returns true
  // to make sure the filesystem was mounted.
  if (!fatfs.begin(&Arcada_QSPI_Flash)) {
    Serial.println("Error, failed to mount newly formatted filesystem!");
    Serial.println("Was the flash chip formatted with the fatfs_format example?");
    while(1);
  }
  Serial.println("Mounted filesystem!");

  arcada.display->setTextColor(ARCADA_WHITE);
  arcada.display->println("Sensors Found: ");
  init_gps(DEBUG);
  arcada.display->println("GPS...ONLINE");
  init_bmp280(DEBUG);
  init_lis3mdl(DEBUG);
  init_lsm6ds33(DEBUG);
  init_sht30(DEBUG);
  arcada.display->println("Sensors...ONLINE");
  init_lora(DEBUG);
  arcada.display->println("LoRa...ONLINE");

  Serial.println("Setup Process Comlplete.");
  arcada.display->setTextColor(ARCADA_GREEN);
  arcada.display->println("Bootup Complete!");
  delay(5000);
  arcada.display->fillScreen(ARCADA_BLACK);
}

/*=====================================================
* Main Loop
=========================================================*/

int16_t packetnum = 0;  // packet counter, we increment per transmission

void loop() {
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

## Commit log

2021-07-23 Added Radiohead library and fixed issues so it compiles
    [main.cpp]
2021-07-25 bug fixes
    bug fixes on some things not working on hardware
    [main.cpp]
2021-08-13 Fix GPS, add Watchdog
    Did a fix to the GPS unit so it should work at high altitudes. Added a Watchdog feature in case the board locks up to reset after 10 seconds.
    [main.cpp]
2021-10-01 Initial commit for hardware development
    [HAR_Board.kicad_pcb, HAR_Board.sch]
2022-03-28 Minor update
    Changed the filename and a few minor fixes based on last flight. Updated FW revision number
    [main.cpp]
2022-06-30 Setup for new KiCad files
    [HAR_Board.kicad_pcb, HAR_Board.sch]
2022-07-01 Initial commit of KiCad files
    [CluePCB.kicad_pcb, CluePCB.kicad_sch]
2022-07-07 Add files via upload
    New voltage divider changes
    [CluePCB.kicad_pcb, CluePCB.kicad_sch]
2022-11-06 Reorganization
    Reorganization of files to prepare the repo for some future automation and to serve as a potential template for future projects.
    [CluePCB.kicad_pcb, CluePCB.kicad_sch]
2022-11-06 first draft on schematic
    [CluePCB.kicad_sch]
2023-07-13 First version of HAR code for MicroMod board.
2023-07-25 Fixed errors. Added commented lines for sensor data and battery voltage.
    [main.ino]
2023-07-25 Updated BME 680 initialization. Sensor works now!
2023-07-28 Uploading early version of ground station code
2023-08-10 Changed radio output power and added decimals to sent data.
2023-10-05 Revised data string format. Changed GNSS dynamic model. Added dynamic pressure sensor functionality.
2023-11-04 Added SD card datalogging to HAR script. Needs testing! Removed lines for unnecessary sensors. Changed GPS initialization and changed how variables are called in loop.
2023-11-11 Changed library used for SD card storage. Still not working.
    [main.ino]
2023-11-21 Solved issues with SD card datalogging. Began implementation of receiver code on HAR.
    [main.ino]
2023-11-22 Implemented basic structure for sending commands from ground station to HAR. Needs further work.
2024-02-21 Added watchdog timer to HAR main code.
2026-04-02 the files for teh kicad project weren't imported properly
2026-04-02 adding the updated pcb files again
    [MicroMod-LoRa-1W-Function-Board.kicad_pcb, MicroMod-LoRa-1W-Function-Board.kicad_sch]

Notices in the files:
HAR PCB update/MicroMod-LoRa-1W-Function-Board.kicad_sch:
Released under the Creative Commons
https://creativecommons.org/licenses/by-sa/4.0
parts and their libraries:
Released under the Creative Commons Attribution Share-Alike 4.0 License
